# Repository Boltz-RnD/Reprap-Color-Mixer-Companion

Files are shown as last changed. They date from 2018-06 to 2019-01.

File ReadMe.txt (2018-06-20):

RCMC

RepRap Color Mixer Companion

"RCMC Gen 1" Is an External I2C Module, which is Developed to control the color output on a color Mixing hotend.

The hex code of the color output required is sent through i2c port and the RCMC automatically tunes the flow rate of the colors Cyan,Yellow,Margenta, White and black, to give the respective output.

RCMC has two Connectors which connects to the driver board

1.Stepper Driver connector shield
   
This shield Connector fits upon your printer board's(eg. RAMPS) extruder's stepper driver's connector and recieves the steps (signal) sent by the printer board.

2.I2C Connector

This Connector is used by RCMC to recieve the color command.

The CPU, based on the color Selected and Stepper driver's signal pulses calculates the resultant flow rates for diffrent Colors , and hence we get multicolor output.

We made this device as a companion to our 1st Gen Hotend and was closed source first, but since we also started by using reprap designs and the community's help, we decided to make RCMC open Source and give something back to the Community.

Feel free to contribute,remix,improve and adapt this work :) .

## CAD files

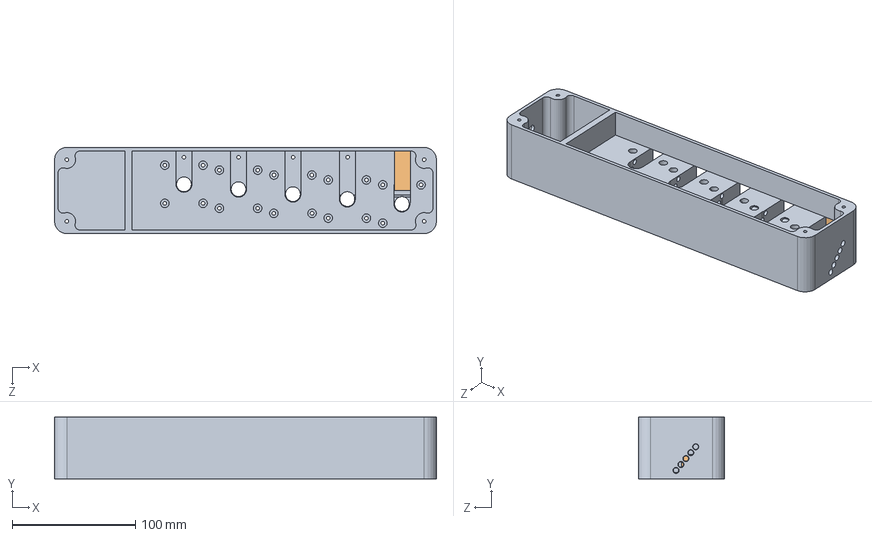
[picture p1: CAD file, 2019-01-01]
Hardware/Reprap Multiple Filament Delivery System/Assem1.SLDASM
310.0 x 50.0 x 70.0 mm
Main Body
BearingSlotP1
BearingSlotP2

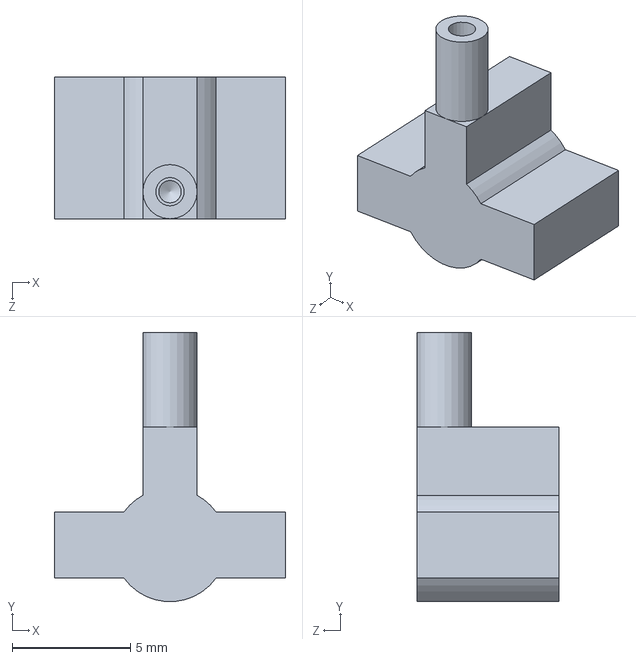
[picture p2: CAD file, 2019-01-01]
Hardware/Reprap Multiple Filament Delivery System/BearingSlotP2.SLDPRT
9.80 x 11.4 x 6.00 mm

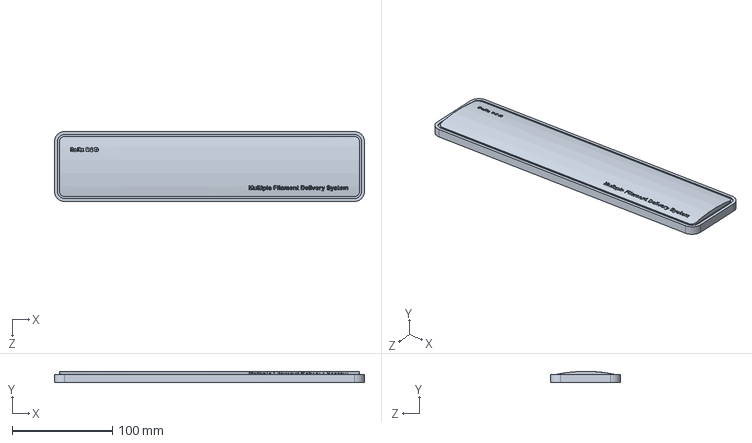
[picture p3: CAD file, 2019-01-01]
Hardware/Reprap Multiple Filament Delivery System/Cap Cover.SLDPRT
310.0 x 11.2 x 70.0 mm

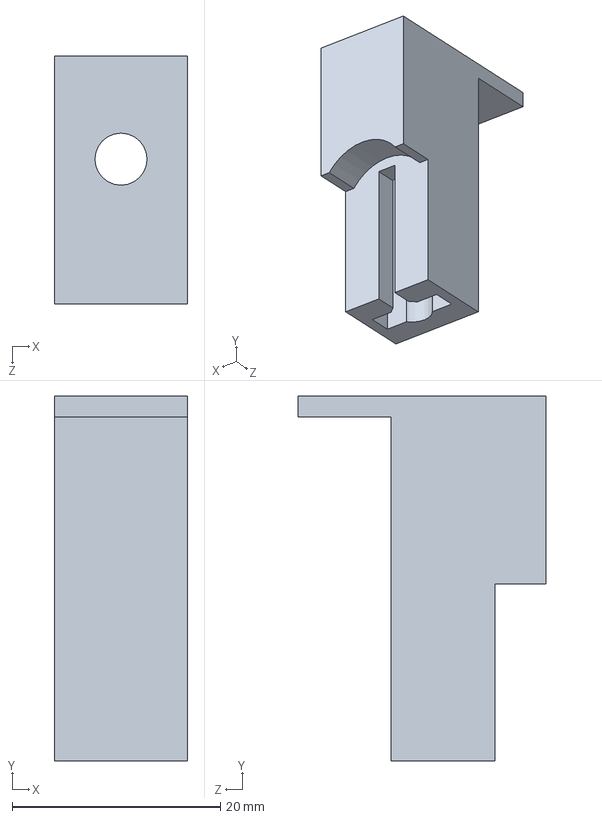
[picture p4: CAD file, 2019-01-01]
Hardware/Reprap Multiple Filament Delivery System/BearingSlotP1.SLDPRT
12.8 x 35.1 x 23.8 mm

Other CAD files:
Hardware/Reprap Multiple Filament Delivery System/Main Body.SLDPRT
Hardware/Reprap Multiple Filament Delivery System/Part1.sldprt
Hardware/Reprap Multiple Filament Delivery System/Main Body.IGS

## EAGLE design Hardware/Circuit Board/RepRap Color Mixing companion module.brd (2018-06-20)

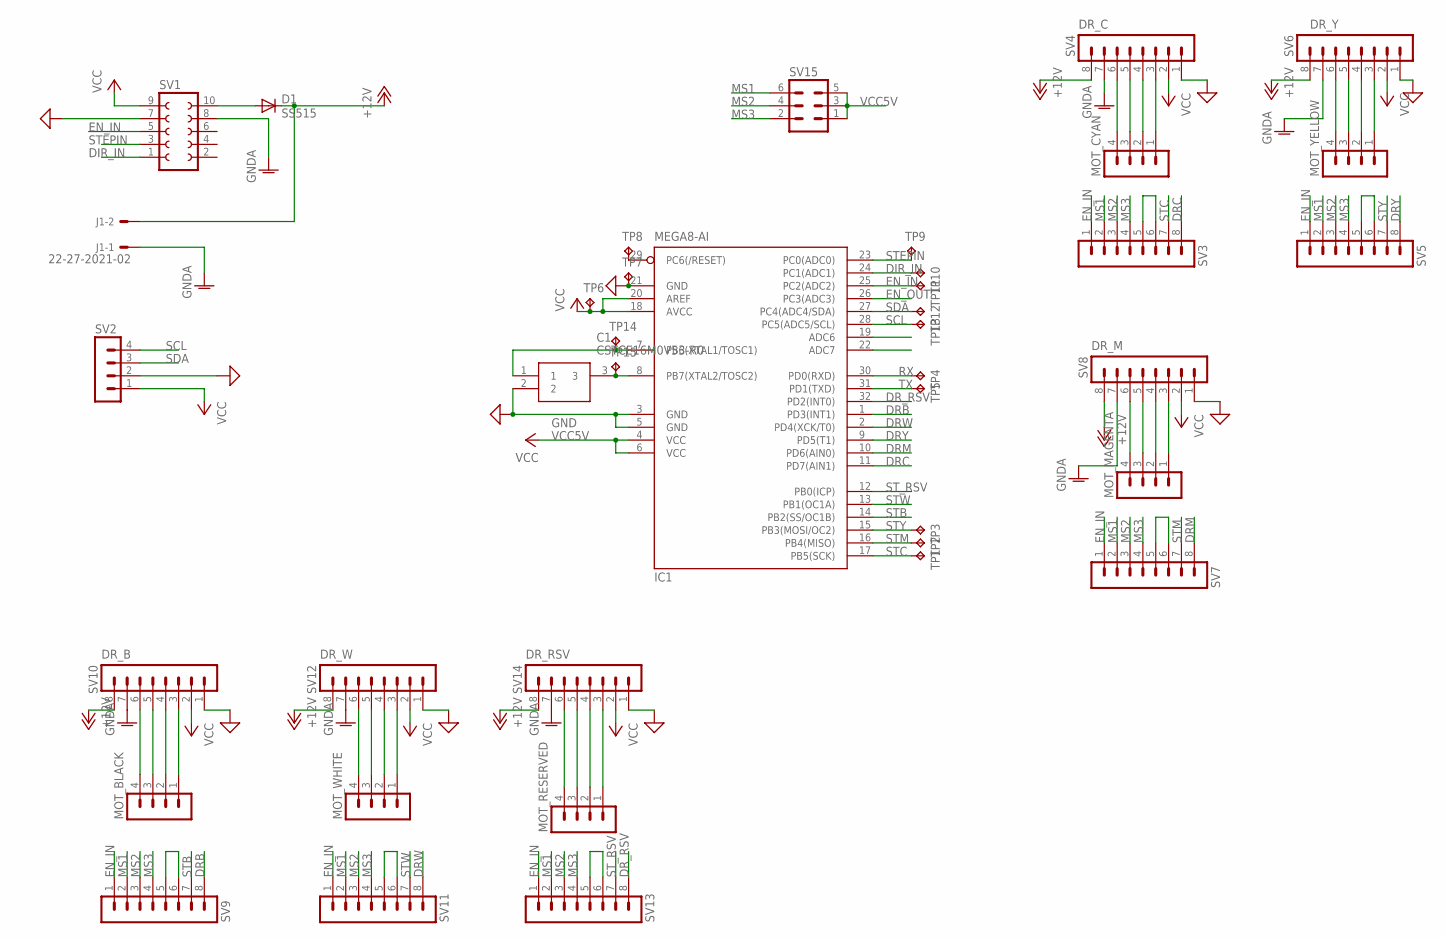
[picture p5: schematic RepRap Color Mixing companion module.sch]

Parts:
C1: CSTCE16M0V53-R0; CSTCE-V
D1: SS515; SMC
IC1: MEGA8-AI; TQFP32-08
J1: 22-27-2021-02; 6410-02
MOT_BLACK: MA04-1
MOT_CYAN: MA04-1
MOT_MAGENTA: MA04-1
MOT_RESERVED: MA04-1
MOT_WHITE: MA04-1
MOT_YELLOW: MA04-1
SV1: FE05-2
SV2: MA04-1
SV3, SV4, SV5, SV6, SV7, SV8, SV9, SV10, SV11, SV12, SV13, SV14: MA08-1
SV15: MA03-2
TP1, TP2, TP3, TP4, TP5, TP6, TP7, TP8, TP9, TP10, TP11, TP12, TP13, TP14, TP15: TPB1,27; B1,27

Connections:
+12V: D1.C, J1.2, SV4.8, SV6.8, SV8.8, SV10.8, SV12.8, SV14.8
DIR_IN: IC1.24 (PC1(ADC1)), SV1.1, TP10.TP
DRB: IC1.1 (PD3(INT1)), SV9.8
DRC: IC1.11 (PD7(AIN1)), SV3.8
DRM: IC1.10 (PD6(AIN0)), SV7.8
DRW: IC1.2 (PD4(XCK/T0)), SV11.8
DRY: IC1.9 (PD5(T1)), SV5.8
DR_RSV: IC1.32 (PD2(INT0)), SV13.8
EN_IN: IC1.25 (PC2(ADC2)), SV1.5, SV3.1, SV5.1, SV7.1, SV9.1, SV11.1, SV13.1, TP11.TP
EN_OUT: IC1.26 (PC3(ADC3))
GND: C1.2, IC1.3 (GND), IC1.5 (GND), IC1.21 (GND), SV1.7, SV2.2, SV4.1, SV6.1, SV8.1, SV10.1, SV12.1, SV14.1, TP7.TP
GNDA: J1.1, SV1.8, SV4.7, SV6.7, SV8.7, SV10.7, SV12.7, SV14.7
MS1: SV3.2, SV5.2, SV7.2, SV9.2, SV11.2, SV13.2, SV15.6
MS2: SV3.3, SV5.3, SV7.3, SV9.3, SV11.3, SV13.3, SV15.4
MS3: SV3.4, SV5.4, SV7.4, SV9.4, SV11.4, SV13.4, SV15.2
unnamed: C1.3, IC1.8 (PB7(XTAL2/TOSC2)), TP15.TP
unnamed: C1.1, IC1.7 (PB6(XTAL1/TOSC1)), TP14.TP
unnamed: IC1.29 (PC6(/RESET)), TP8.TP
unnamed: D1.A, SV1.10
unnamed: SV3.5, SV3.6
unnamed: MOT_CYAN.1, SV4.3
unnamed: MOT_CYAN.2, SV4.4
unnamed: MOT_CYAN.3, SV4.5
unnamed: MOT_CYAN.4, SV4.6
unnamed: SV5.5, SV5.6
unnamed: MOT_YELLOW.1, SV6.3
unnamed: MOT_YELLOW.2, SV6.4
unnamed: MOT_YELLOW.3, SV6.5
unnamed: MOT_YELLOW.4, SV6.6
unnamed: SV7.5, SV7.6
unnamed: MOT_MAGENTA.1, SV8.3
unnamed: MOT_MAGENTA.2, SV8.4
unnamed: MOT_MAGENTA.3, SV8.5
unnamed: MOT_MAGENTA.4, SV8.6
unnamed: SV9.5, SV9.6
unnamed: MOT_BLACK.1, SV10.3
unnamed: MOT_BLACK.2, SV10.4
unnamed: MOT_BLACK.3, SV10.5
unnamed: MOT_BLACK.4, SV10.6
unnamed: SV11.5, SV11.6
unnamed: MOT_WHITE.1, SV12.3
unnamed: MOT_WHITE.2, SV12.4
unnamed: MOT_WHITE.3, SV12.5
unnamed: MOT_WHITE.4, SV12.6
unnamed: SV13.5, SV13.6
unnamed: MOT_RESERVED.1, SV14.3
unnamed: MOT_RESERVED.2, SV14.4
unnamed: MOT_RESERVED.3, SV14.5
unnamed: MOT_RESERVED.4, SV14.6
RX: IC1.30 (PD0(RXD)), TP4.TP
SCL: IC1.28 (PC5(ADC5/SCL)), SV2.4, TP13.TP
SDA: IC1.27 (PC4(ADC4/SDA)), SV2.3, TP12.TP
STB: IC1.14 (PB2(SS/OC1B)), SV9.7
STC: IC1.17 (PB5(SCK)), SV3.7, TP1.TP
STEPIN: IC1.23 (PC0(ADC0)), SV1.3, TP9.TP
STM: IC1.16 (PB4(MISO)), SV7.7, TP2.TP
STW: IC1.13 (PB1(OC1A)), SV11.7
STY: IC1.15 (PB3(MOSI/OC2)), SV5.7, TP3.TP
ST_RSV: IC1.12 (PB0(ICP)), SV13.7
TX: IC1.31 (PD1(TXD)), TP5.TP
VCC: IC1.18 (AVCC), IC1.20 (AREF), SV1.9, SV2.1, SV4.2, SV6.2, SV8.2, SV10.2, SV12.2, SV14.2, TP6.TP
VCC5V: IC1.4 (VCC), IC1.6 (VCC), SV15.1, SV15.3, SV15.5

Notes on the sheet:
DR_C
DR_Y
DR_M
DR_B
DR_W
DR_RSV

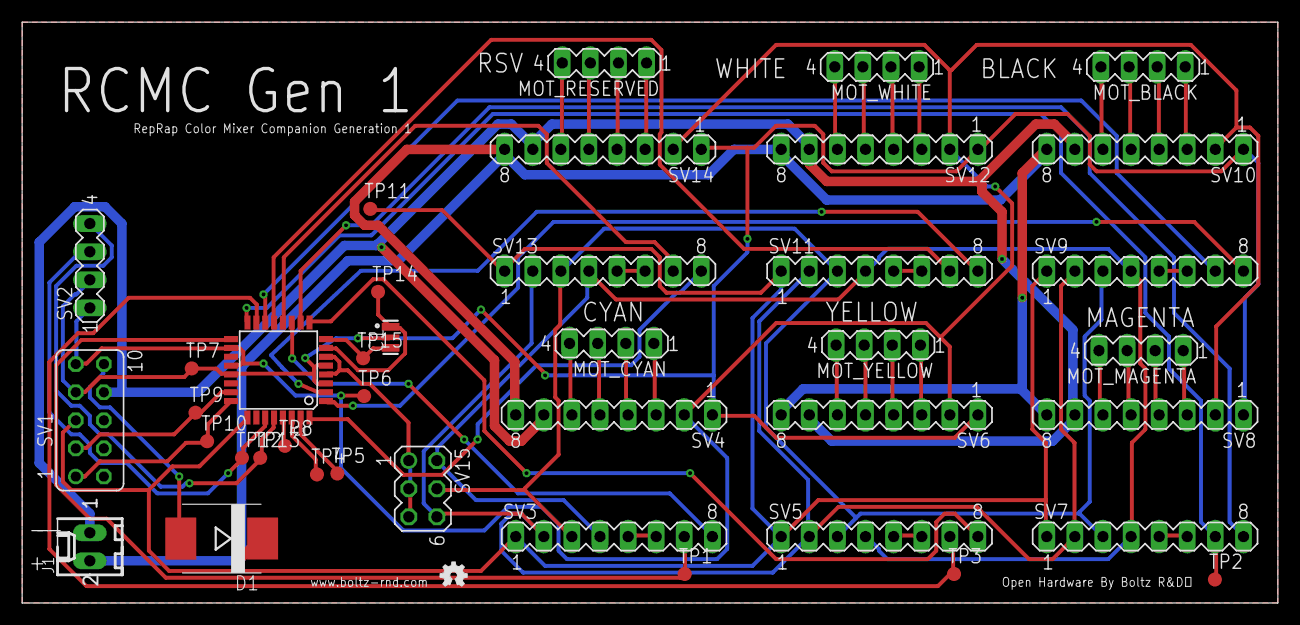
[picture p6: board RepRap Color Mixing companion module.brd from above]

Board: 2 copper layers, 113.5 x 52.5 mm, 41 parts (0 on the bottom side), 61 nets.

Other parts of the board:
U$2: OSHW-LOGO-MINI

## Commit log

2018-06-20 Added Files
    Added Board file and Schematics Files
    [RepRap Color Mixing companion module.brd, RepRap Color Mixing companion module.sch]
2019-01-01 Organized Folders and Added CAD Files of MFDS
    Organized Folders and Added CAD Files of Multiple Filament Delivery System.
    [Assem1.SLDASM, BearingSlotP1.SLDPRT, BearingSlotP2.SLDPRT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]

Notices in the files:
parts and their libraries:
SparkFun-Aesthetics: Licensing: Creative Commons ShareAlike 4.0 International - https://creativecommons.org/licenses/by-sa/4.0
